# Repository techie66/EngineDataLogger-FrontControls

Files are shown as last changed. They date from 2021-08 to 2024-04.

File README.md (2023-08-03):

# Engine Data Logger - Front Controls

## Componenents
- [EngineDataLogger(EDL)](https://github.com/techie66/EngineDataLogger)
- [EDL - Dashboard](https://github.com/techie66/EngineDataLogger---Dashboard)
- ->[EDL - Front Controls](https://github.com/techie66/EngineDataLogger-FrontControls)
- [EDL - EngineData](https://github.com/techie66/EngineDataLogger-EngineData)

# Dependencies
- Seeed Studio CAN Library `git clone "https://github.com/Seeed-Studio/Seeed_Arduino_CAN.git"`
- NeoSWSerial `git clone "git@github.com:SlashDevin/NeoSWSerial.git"`

# License
EngineDataLogger is licensed under the GNU GPLv2. Dependencies are licensed under their respective licenses. See LICENSE for full text of GPLv2.

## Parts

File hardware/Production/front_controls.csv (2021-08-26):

Reference | Quantity | Value | Footprint | Datasheet | LCSC | Field4
A1 | 1 | Arduino_Nano_v3.x | NANO:Arduino_Nano | http://www.mouser.com/pdfdocs/Gravitech_Arduino_Nano3_0.pdf
C10 C9 C8 C7 C6 C5 C1 C2 C3 | 9 | .01uf | Capacitor_SMD:C_0402_1005Metric |  | C15195
C11 C12 | 2 | 33pf | Capacitor_SMD:C_0402_1005Metric | https://datasheet.lcsc.com/szlcsc/Guangdong-Fenghua-Advanced-Tech-0402CG330J500NT_C1562.pdf | C1562
C13 C14 C15 C16 | 4 | 100nf | Capacitor_SMD:C_0402_1005Metric | https://datasheet.lcsc.com/szlcsc/Samsung-Electro-Mechanics-CL05B104KO5NNNC_C1525.pdf | C1525
C17 | 1 | 330uf | Capacitor_THT:CP_Radial_D8.0mm_P3.50mm
C18 | 1 | 22nF | Capacitor_SMD:C_0603_1608Metric |  | C21122
C4 | 1 | .1uf | Capacitor_SMD:C_0402_1005Metric |  | C1525
Cboot1 | 1 | 0.1uf | Capacitor_SMD:C_0402_1005Metric |  | C1525
Chf1 | 1 | 220nf | Capacitor_SMD:C_0805_2012Metric |  | C5378
Cin1 | 1 | 10uf | Capacitor_SMD:C_0805_2012Metric |  | C440198
Cout1 Cout2 Cout3 Cout4 | 4 | 22uF | Capacitor_SMD:C_0805_2012Metric |  | C45783
D13 D12 D11 D10 D9 D8 | 6 | 4.7V Zener | Diode_SMD:D_SOD-323 |  | C136181
D19 D18 D17 D16 D15 D14 D1 D2 D3 D4 D5 D6 | 12 | D_Schottky | Diode_SMD:D_SOD-123 |  | C8598
D20 | 1 | 15V standoff | Diode_SMD:D_SMB | https://datasheet.lcsc.com/szlcsc/MDD-Jiangsu-Yutai-Elec-SMBJ15CA_C113989.pdf | C113989
D21 | 1 | 8A | Diode_SMD:D_SMC |  | C64338
D7 | 1 | 5.1V Zener | Diode_SMD:D_SOD-123 |  | C231290
H1 | 1 | CONN_01X10 | Pin_Headers:Pin_Header_Straight_1x10
H2 | 1 | HM-10 | Connector_PinSocket_2.54mm:PinSocket_1x06_P2.54mm_Vertical | ~
H3 | 1 | Expansion | Connector_PinHeader_2.54mm:PinHeader_2x08_P2.54mm_Vertical
H6 H5 H4 H7 | 4 | MountingHole | MountingHole:MountingHole_2.7mm_M2.5 | ~
J1 J2 J3 J4 J5 J6 J7 J8 J9 | 9 | Conn_01x02 | Connector_JST:JST_EH_B2B-EH-A_1x02_P2.50mm_Vertical
J10 J11 | 2 | CAN | Connector_JST:JST_EH_B2B-EH-A_1x02_P2.50mm_Vertical
JP1 | 1 | Jumper_NO_Small | Jumper:SolderJumper-2_P1.3mm_Open_RoundedPad1.0x1.5mm
L1 | 1 | 8.2uH, 60m | Inductor_SMD:L_Bourns_SRP7028A_7.3x6.6mm |  | C408450
P2 P1 | 2 | PWR | Connector_JST:JST_EH_B2B-EH-A_1x02_P2.50mm_Vertical
R0 R1 R2 R3 R4 R5 R6 R7 R8 | 9 | 500R | Resistor_SMD:R_0402_1005Metric |  | C25130
R11 R45 | 2 | 4k7 | Resistor_SMD:R_0603_1608Metric |  | C23162
R37 R34 R31 R28 R25 R22 R13 R17 R21 R43 R44 R47 | 12 | 100k | Resistor_SMD:R_0402_1005Metric |  | C25741
R38 R35 R32 R29 R26 R23 R12 R16 R20 R19 R15 R10 R18 R14 R9 | 15 | 1k | Resistor_SMD:R_0402_1005Metric |  | C11702
R39 R36 R33 R30 R27 R24 | 6 | 10R | Resistor_SMD:R_0402_1005Metric |  | C25077
R40 | 1 | 10k | Resistor_SMD:R_0603_1608Metric |  | C25804
R41 | 1 | 2k2 | Resistor_SMD:R_0603_1608Metric |  | C4190
R42 | 1 | 4K7 1% | Resistor_SMD:R_0402_1005Metric | https://datasheet.lcsc.com/szlcsc/Uniroyal-Elec-0402WGF4701TCE_C25900.pdf | C25900
R46 | 1 | 120R | Resistor_SMD:R_0402_1005Metric |  | C25079
R48 | 1 | 62K11 | Resistor_SMD:R_0603_1608Metric | ~ | C23221
Rfbb1 | 1 | 17k8 1% | Resistor_SMD:R_0402_1005Metric |  | C129766
Rfbt1 | 1 | 100k 1% | Resistor_SMD:R_0402_1005Metric |  | C25741
U1 | 1 | TXB0104PW | Package_SO:TSSOP-14_4.4x5mm_P0.65mm | http://www.ti.com/lit/ds/symlink/txb0104.pdf | C60708
U11 | 1 | LMR14030SDDA | NANO:LMR14030SDDA |  | C182078
U13 | 1 | MCP23017-E/SO | Package_SO:SOIC-28W_7.5x18.7mm_P1.27mm | https://datasheet.lcsc.com/szlcsc/Microchip-Tech-MCP23017-E-SO_C47023.pdf | C47023
U14 | 1 | MCP2515-xSO | Package_SO:SOIC-18W_7.5x11.6mm_P1.27mm | http://ww1.microchip.com/downloads/en/DeviceDoc/21801e.pdf | C12368
U15 | 1 | TJA1051T | Package_SO:SOIC-8_3.9x4.9mm_P1.27mm | http://www.nxp.com/documents/data_sheet/TJA1051.pdf | C6952
U6 U9 U8 U7 U5 U4 U10 U3 U2 | 9 | G3VM-31BR | G3VM-31BR:DIP762W50P254L737H485Q6 | IPC-7251 |  | OMRON
Y1 | 1 | 12Mhz | Crystal:Crystal_SMD_3225-4Pin_3.2x2.5mm | https://datasheet.lcsc.com/szlcsc/Yangxing-Tech-X322512MSB4SI_C9002.pdf | C9002

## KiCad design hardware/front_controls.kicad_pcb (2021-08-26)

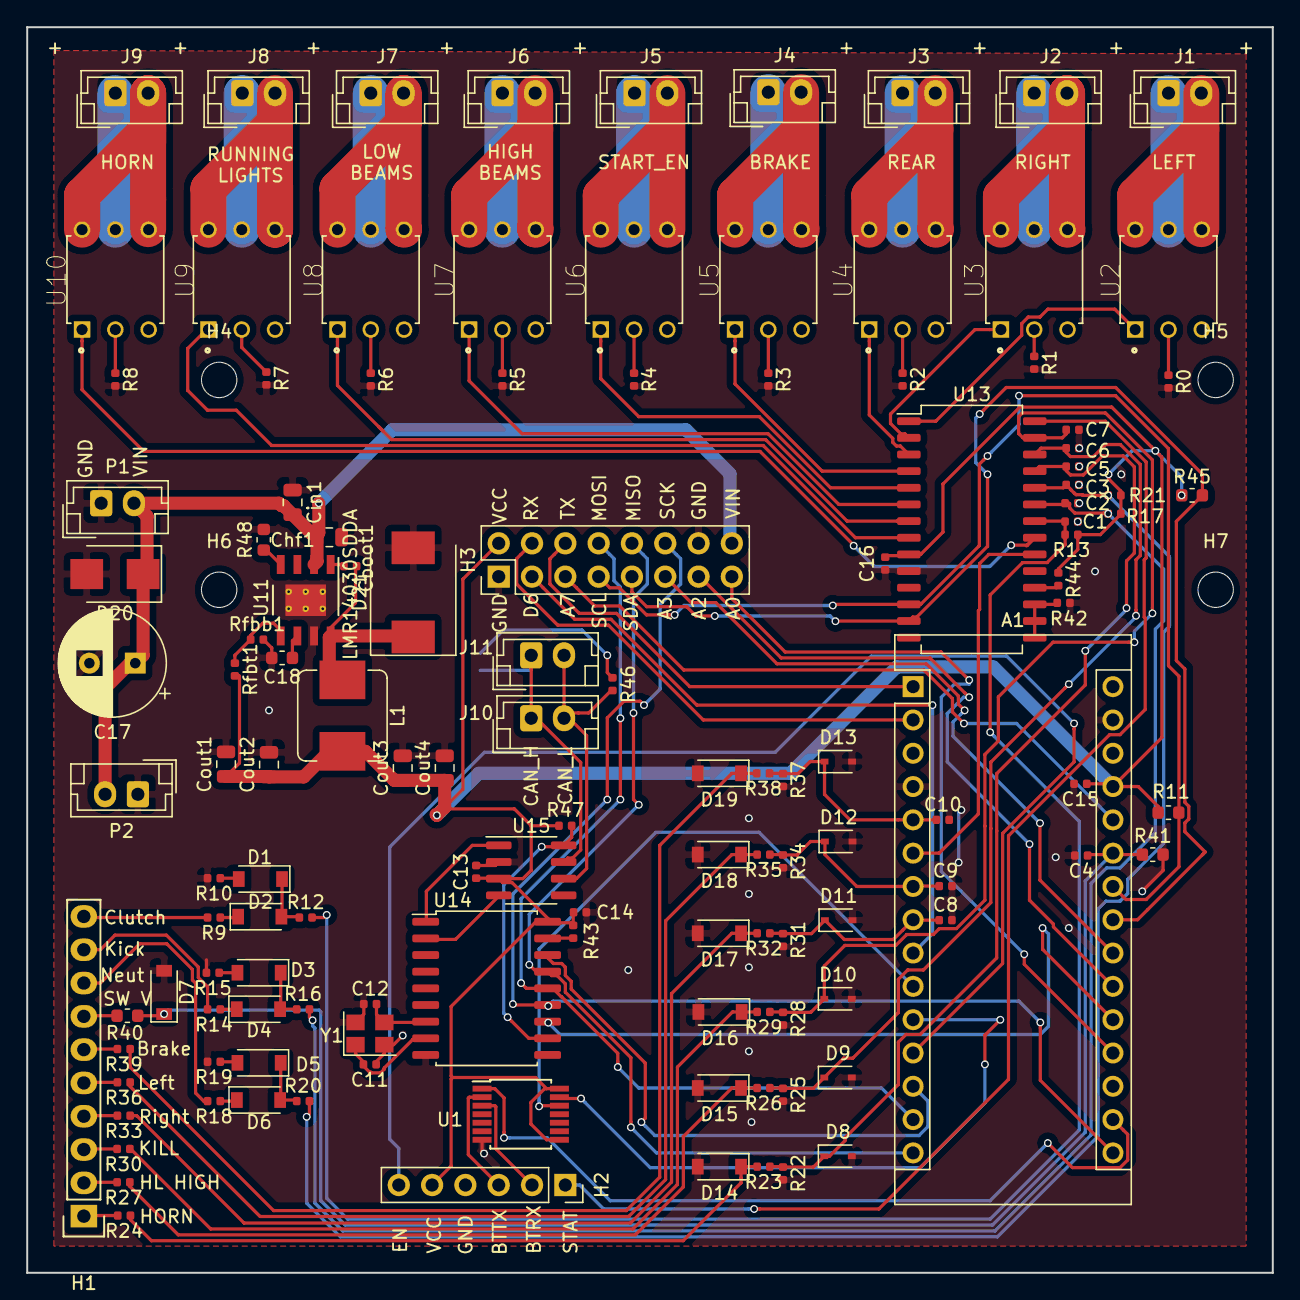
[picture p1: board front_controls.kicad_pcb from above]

Board: 2 copper layers, 95.0 x 95.0 mm, 135 parts (1 on the bottom side), 112 nets.

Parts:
A1: Arduino_Nano_v3.x; Arduino_Nano
C1, C2, C3, C5, C6, C7, C8, C9, C10: .01uf; C_0402_1005Metric
C4: .1uf; C_0402_1005Metric
C11, C12: 33pf; C_0402_1005Metric
C13, C14, C15, C16: 100nf; C_0402_1005Metric
C17: 330uf; CP_Radial_D8.0mm_P3.50mm
C18: 22nF; C_0603_1608Metric
Cboot1: 0.1uf; C_0402_1005Metric
Chf1: 220nf; C_0805_2012Metric
Cin1: 10uf; C_0805_2012Metric
Cout1, Cout2, Cout3, Cout4: 22uF; C_0805_2012Metric
D1, D2, D3, D4, D5, D6, D14, D15, D16, D17, D18, D19: D_Schottky; D_SOD-123
D7: 5.1V Zener; D_SOD-123
D8, D9, D10, D11, D12, D13: 4.7V Zener; D_SOD-323
D20: 15V standoff; D_SMB
D21: 8A; D_SMC
H1: CONN_01X10; Pin_Header_Straight_1x10
H2: HM-10; PinSocket_1x06_P2.54mm_Vertical
H3: Expansion; PinHeader_2x08_P2.54mm_Vertical
H4, H5, H6, H7: MountingHole; MountingHole_2.7mm_M2.5
J1, J2, J3, J4, J5, J6, J7, J8, J9: Conn_01x02; JST_EH_B2B-EH-A_1x02_P2.50mm_Vertical
J10, J11: CAN; JST_EH_B2B-EH-A_1x02_P2.50mm_Vertical
JP1: Jumper_NO_Small; SolderJumper-2_P1.3mm_Open_RoundedPad1.0x1.5mm
L1: 8.2uH, 60m; L_Bourns_SRP7028A_7.3x6.6mm
P1, P2: PWR; JST_EH_B2B-EH-A_1x02_P2.50mm_Vertical
R0, R1, R2, R3, R4, R5, R6, R7, R8: 500R; R_0402_1005Metric
R9, R10, R12, R14, R15, R16, R18, R19, R20, R23, R26, R29, R32, R35, R38: 1k; R_0402_1005Metric
R11, R45: 4k7; R_0603_1608Metric
R13, R17, R21, R22, R25, R28, R31, R34, R37, R43, R44, R47: 100k; R_0402_1005Metric
R24, R27, R30, R33, R36, R39: 10R; R_0402_1005Metric
R40: 10k; R_0603_1608Metric
R41: 2k2; R_0603_1608Metric
R42: 4K7 1%; R_0402_1005Metric
R46: 120R; R_0402_1005Metric
R48: 62K11; R_0603_1608Metric
Rfbb1: 17k8 1%; R_0402_1005Metric
Rfbt1: 100k 1%; R_0402_1005Metric
U1: TXB0104PW; TSSOP-14_4.4x5mm_P0.65mm
U2, U3, U4, U5, U6, U7, U8, U9, U10: G3VM-31BR; DIP762W50P254L737H485Q6
U11: LMR14030SDDA
U13: MCP23017-E/SO; SOIC-28W_7.5x18.7mm_P1.27mm
U14: MCP2515-xSO; SOIC-18W_7.5x11.6mm_P1.27mm
U15: TJA1051T; SOIC-8_3.9x4.9mm_P1.27mm
Y1: 12Mhz; Crystal_SMD_3225-4Pin_3.2x2.5mm

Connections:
/3V3: A1.17, U1.1
/BT_EN: A1.12, H2.6
/BT_RX_H: A1.10, U1.12
/BT_RX_L: H2.2, U1.3
/BT_STATE: H2.1, U13.28
/BT_TX_H: A1.11, U1.13
/BT_TX_L: H2.3, U1.2
/CAN_H: J10.1, J11.1, JP1.1, U15.7
/CAN_INT: A1.20, U14.12
/CAN_L: J10.2, J11.2, R46.1, U15.6
/EN_TX: R47.1, U14.11, U15.8
/INTA1: A1.6, U13.20
/IN_AN1: A1.25, C4.1, D7.1, R40.2, R41.1
/IN_BRAKE: A1.5, C10.1, D13.1, R37.1, R38.1
/IN_CLUTCH: C1.1, R12.2, R13.2, U13.22
/IN_HL_HIGH: C6.1, D9.1, R25.1, R26.1, U13.26
/IN_HORN: C5.1, D8.1, R22.1, R23.1, U13.25
/IN_KICK: C2.1, R16.2, R17.2, U13.23
/IN_KILL: C7.1, D10.1, R28.1, R29.1, U13.27
/IN_LEFT: A1.7, C9.1, D12.1, R34.1, R35.1
/IN_NEUTRAL: C3.1, R20.2, R21.2, U13.24
/IN_RIGHT: A1.8, C8.1, D11.1, R31.1, R32.1
/MCU_A0: A1.19, H3.15
/MCU_A2: A1.21, H3.13
/MCU_A3: A1.22, H3.11
/MCU_A7: A1.26, H3.5
/MCU_D6: A1.9, H3.3
/OUT_BRAKE: U5.1, U13.4
/OUT_HL_HIGH: U7.1, U13.6
/OUT_HL_LOW: U8.1, U13.7
/OUT_HORN: U10.1, U13.21
/OUT_LEFT: U2.1, U13.1
/OUT_REAR: U4.1, U13.3
/OUT_RIGHT: U3.1, U13.2
/OUT_RUNNING: U9.1, U13.8
/OUT_START_EN: U6.1, U13.5
/RXCAN: U14.2, U15.4
/SCL: A1.24, H3.7, R11.1, U13.12
/SDA: A1.23, H3.9, R45.2, U13.13
/SPI_CS: A1.13, U14.16
/SPI_SCK: A1.16, H3.12, U14.13
/SPI_SI: A1.14, H3.8, U14.14
/SPI_SO: A1.15, H3.10, U14.15
/TXCAN: U14.1, U15.1
/UART_RX: A1.2, H3.4
/UART_TX: A1.1, H3.6
/VIN: C17.1, Chf1.2, Cin1.2, D20.1, H3.16, P1.2, P2.2, U11.2
GND: A1.4, A1.29, C1.2, C2.2, C3.2, C4.2, C5.2, C6.2, C7.2, C8.2, C9.2, C10.2, C11.1, C12.1, C13.2, C14.1, C15.2, C16.2, C17.2, C18.2, Chf1.1, Cin1.1, Cout1.2, Cout2.2, Cout3.2, Cout4.2, D7.2, D8.2, D9.2, D10.2, D11.2, D12.2, D13.2, D14.2, D15.2, D16.2, D17.2, D18.2, D19.2, D20.2, D21.2, H2.4, H3.1, H3.14, P1.1, P2.1, R0.2, R1.2, R2.2, R3.2, R4.2, R5.2, R6.2, R7.2, R8.2, R10.2, R15.2, R19.2, R22.2, R25.2, R28.2, R31.2, R34.2, R37.2, R41.2, R42.2, R48.2, Rfbb1.2, U1.7, U11.7, U11.9, U13.10, U14.9, U15.2, Y1.2, Y1.4
unnamed: C11.2, U14.8, Y1.1
unnamed: C12.2, U14.7, Y1.3
unnamed: C18.1, U11.6
unnamed: Cboot1.1, U11.1
unnamed: Cboot1.2, D21.1, L1.1, U11.8
unnamed: D1.1, R9.1
unnamed: D1.2, D2.1, R12.1
unnamed: D2.2, R10.1
unnamed: D3.1, R14.1
unnamed: D3.2, D4.1, R16.1
unnamed: D4.2, R15.1
unnamed: D5.1, R18.1
unnamed: D5.2, D6.1, R20.1
unnamed: D6.2, R19.1
unnamed: D14.1, R23.2, R24.1
unnamed: D15.1, R26.2, R27.1
unnamed: D16.1, R29.2, R30.1
unnamed: D17.1, R32.2, R33.1
unnamed: D18.1, R35.2, R36.1
unnamed: D19.1, R38.2, R39.1
unnamed: H1.1, R24.2
unnamed: H1.2, R27.2
unnamed: H1.3, R30.2
unnamed: H1.4, R33.2
unnamed: H1.5, R36.2
unnamed: H1.6, R39.2
unnamed: H1.7, R40.1
unnamed: H1.8, R18.2
unnamed: H1.9, R14.2
unnamed: H1.10, R9.2
unnamed: J1.1, U2.5
unnamed: J1.2, U2.6
unnamed: J2.1, U3.5
unnamed: J2.2, U3.6
unnamed: J3.1, U4.5
unnamed: J3.2, U4.6
unnamed: J4.1, U5.5
unnamed: J4.2, U5.6
unnamed: J5.1, U6.5
unnamed: J5.2, U6.6
unnamed: J6.1, U7.5
unnamed: J6.2, U7.4, U7.6
unnamed: J7.1, U8.5
unnamed: J7.2, U8.4, U8.6
unnamed: J8.1, U9.5
unnamed: J8.2, U9.6
unnamed: J9.1, U10.5
unnamed: J9.2, U10.6
unnamed: JP1.2, R46.2
unnamed: R0.1, U2.2
unnamed: R1.1, U3.2
unnamed: R2.1, U4.2
unnamed: R3.1, U5.2
unnamed: R4.1, U6.2
unnamed: R5.1, U7.2
unnamed: R6.1, U8.2
unnamed: R7.1, U9.2
unnamed: R8.1, U10.2
unnamed: R42.1, U13.15, U13.16, U13.17
unnamed: R43.1, U14.17
unnamed: R44.2, U13.18
unnamed: R48.1, U11.4
unnamed: Rfbb1.1, Rfbt1.1, U11.5
VCC: A1.27, C13.1, C14.2, C15.1, C16.1, Cout1.1, Cout2.1, Cout3.1, Cout4.1, H2.5, H3.2, L1.2, R11.2, R13.1, R17.1, R21.1, R43.2, R44.1, R45.1, R47.2, Rfbt1.2, U1.8, U1.14, U13.9, U14.18, U15.3

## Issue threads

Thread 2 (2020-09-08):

Expand IO / CAN BUS interface

techie66, 2020-09-08:
Possible components:
TJA1050 - High speed CAN transceiver
MCP2551 - High speed CAN transceiver
MCP2515 - SPI CAN controller
MCP2515 - SPI IO expander

techie66, 2021-05-18:
Prototype of hardware V2 is working with I2C MCP23017 expander and MCP2515. New board has header for further IO expansion. Software updated for new hardware. Will close with merge of hardware v2

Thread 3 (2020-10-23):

certain cases ignition enable is wrong state.

techie66, 2020-10-23:
Under certain conditions, yet to be determined, the kill switch must be on to turn off the keyless ignition. ie ignition enable doesn't go high when expected. When bike is started manually then shut off is one such case, which results in forcing the starter to turn over.

techie66, 2022-03-27:
Ignition power integration is possible with V2 board and additional relays on expansion port. No longer relevant even to me.

Closed 2022-03-27.

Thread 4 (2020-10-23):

kickstand logic not right

techie66, 2020-10-23:
Logic is incorrect for kickstand, allowing the bike to be in gear with clutch out and kickstand down.
That condition should disable ignition power.

techie66, 2021-03-16:
This will have to wait until the hardware is updated to actually control ignition power

techie66, 2022-03-27:
With the V2 hardware, which is now fairly old, I added a few relays to to the expansion port, enabling direct control of ignition power and the software supports it as well.

Closed 2022-03-27.

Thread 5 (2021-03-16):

Add voltage regulator on board

techie66, 2021-03-16:
Board is missing direct power, currently draws power from USB. The working prototype doesn't do that, and we need on board voltage regulator.

techie66, 2021-04-22:
Hardware rev 2.0 prototype made with regulator. It's not pushed to GitHub yet until I get a chance to test it.

techie66, 2021-05-18:
Testing has

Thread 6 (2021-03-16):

Integrate keyless ignition

techie66, 2021-03-16:
Prototype has completely separate module for keyless ignition. Ideally that functionality would be included on one board or at least on a daughter board.

techie66, 2021-05-18:
Hardware V2 has headers for hm10 BLE module and additional IO to support this. Just need the software now.

techie66, 2022-03-27:
With newest version of firmware and dashboard app, and the aforementioned BLE module and more relays on the expansion port, proof of concept works. The bike will turn on when the app connects. No security, authentication or anything is implemented yet. Do not use yet IRL

techie66, 2025-01-11:
Still no security, but routines added to use BLE module as CAN bridge that emulates function of CAN-Link. Waits for a specific CAN frame with specific payload in order to turn on main power. ie. less likely to be hacked, but still not secure...

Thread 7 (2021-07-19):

Neutral and clutch swapped

techie66, 2021-07-19:
inputs for neutral and clutch are swapped (?)
need to check it and get the right pins to match labels on the board.
#oops

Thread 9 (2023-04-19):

Feature: add wake (pin change) on switched power

techie66, 2023-04-19:
Should be a simple addition to wake from sleep when switched power goes from 0v to 12v with pin change interrupt.

techie66, 2023-08-19:
3ecf09e adds the feature

Closed 2023-08-19.

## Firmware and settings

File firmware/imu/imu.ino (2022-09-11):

/*

    EngineDataLogger-Front Controls -- component that runs on MCU for front controls
    Copyright (C) 2018-2020  Jacob Geigle jacob@geigle.me

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
    You should have received a copy of the GNU General Public License along
    with this program; if not, write to the Free Software Foundation, Inc.,
    51 Franklin Street, Fifth Floor, Boston, MA 02110-1301 USA.

*/


/*    Basic Idea
 *  loop reads all input pins and checks for serial commands
 *  create command word and sensor data stream
 *  send sensor data (limit rate by time, etc)
 *  call each action function
 *  each function performs small snippet based on command word (smallest action at a time)
 *    use static vars to maintain state (eg blinking = on first time, off second time)
 *    millis() to maintain timing and synchronization
 *  brake light on interrupt
 *    flash initially, steady until low
 *  horn sounds on interrupt
 *  
 *  Pins read full register at a time and bitmasking used heavily to execute commands
 *  
 *  brake()
 *  blinkRight()
 *  blinkLeft()
 *  hornSound()
 *  enableStart()
 *  hlMode()
 *  
 */

#include <avr/interrupt.h>
#include <avr/power.h>
#include <avr/sleep.h>
#include <Wire.h>
#include <mcp2515_can.h>
#include "MPU6050_imu.h"
#include "../pins.h"
#include "spin.h"
#include "../wdt.h"

uint8_t ADCSRA_save = 0;
volatile boolean brakeStart = false;
boolean engineStarted = false;
float systemVoltage = 0;
volatile uint8_t mcpA = 0; // Output buffer for GPIOA
volatile uint8_t mcpB = 0; // Output buffer for GPIOB


const uint8_t RLY_ON = HIGH;
const uint8_t RLY_OFF = LOW;
const unsigned long blinkDelay = 350;
const unsigned long SLEEP_DELAY = 120000;
const unsigned long BRAKE_FLASH_INTERVAL = 50;

//Constants for voltage divider
const int resistor1 = 991; //997 (992 meas)
const int resistor2 = 223; //236 (218 meas)
const float denominator = (float)resistor2 / (resistor1 + resistor2);

// Vars for inputs
bool BRAKE_ON = false;
bool LEFT_ON = false;
bool RIGHT_ON = false;
bool HORN_ON = false;
bool HIGH_BEAMS_ON = false;
bool KILL_ON = false;
bool CLUTCH_DISENGAGED = false;
bool IN_NEUTRAL = false;
bool KICKSTAND_UP = false;

// CAN Constants
const int SPI_CS_PIN = 10;
mcp2515_can CAN(SPI_CS_PIN); // Set CS pin

// Function Prototypes
void sleepNow ();
void readSensors();
ISR(TIMER1_COMPA_vect);
void brakeLight();
void hornSound();
void Wakeup_Routine();
void allRelaysOff ();
void sleepNow ();

void setup() {
  Serial.begin(115200);
  Serial.println("Startup initiated!");
  Wire.begin(); // wake up I2C bus
  Wire.setClock(400000); // 400kHz I2C clock. Comment this line if having compilation difficulties
  #ifdef __AVR__
  Wire.setWireTimeout(3000, true); //timeout value in uSec
  #endif

  Wire.beginTransmission(0x20);
  Wire.write(0x00); // IODIRA register
  Wire.write(0xFE); // set pin 0 of port A to output, 1-7 to input
  Wire.endTransmission();

  Wire.beginTransmission(0x20);
  Wire.write(0x01); // IODIRB register
  Wire.write(0x00); // set all of port B to outputs
  Wire.endTransmission();

  Wire.beginTransmission(0x20);
  Wire.write(0x04); // GPINTENA
  Wire.write(0xFE); // 1-7 enable interrupt
  Wire.endTransmission();

  Wire.beginTransmission(0x20);
  Wire.write(0x02); // IPOLA
  Wire.write(0x0E); // Pins 1-3 Inverted Polarity
  Wire.endTransmission();

  Wire.beginTransmission(0x20);
  Wire.write(0x0C); // GPPUA
  Wire.write(0x0E); // Pins 1-3 Pullup Enabled
  Wire.endTransmission();

  //Serial.println("I2c Done");
  //allRelaysOff();

  pinMode(brakeInPin, INPUT);
  pinMode(leftInPin, INPUT);
  pinMode(rightInPin, INPUT);
  pinMode(voltageInPin, INPUT); // Analog for Voltage
  
  // CAN Setup

  while (CAN_OK != CAN.begin(CAN_500KBPS,MCP_12MHz)) {             // init can bus : baudrate = 500k
	  Serial.println("CAN ERROR");
      delay(100);
  }


  //Serial.println("CAN Done");

  CAN.mcpPinMode(MCP_RX0BF,MCP_PIN_OUT);

  //Serial.println("Startup Complete!");
  //delay(1000);
  MPU_setup();
  Serial.println("MPU Complete");
  Serial.println("Setup Complete\n");

  watchdogSetup();
}
spinner *s = spin_new(utf8_pat1, "Working", UTF8_CHAR_WIDTH);

void loop() {
  wdt_reset();
  spin_drw(s);
  delay(50);
  // if programming failed, don't try to do anything
  if (!dmpReady) return;
  // read a packet from FIFO
  if (mpu.dmpGetCurrentFIFOPacket(fifoBuffer)) { // Get the Latest packet 

    // display Euler angles in degrees
    mpu.dmpGetQuaternion(&q, fifoBuffer);
    mpu.dmpGetGravity(&gravity, &q);
    mpu.dmpGetYawPitchRoll(ypr, &q, &gravity);
    uint16_t roll = ( (ypr[2] * 180 / M_PI) + 180 ) * 10;
    uint16_t pitch = ( (ypr[1] * 180 / M_PI) + 180 ) * 10;
    uint16_t yaw = ( (ypr[0] * 180 / M_PI) + 360 ) * 10;
    // Send CAN Packets
    static unsigned char stmp[8] = {0xCC, 0xCC, 0xCC, 0xCC, 0xCC, 0xCC, 0xCC, 0xCC};
      stmp[0] = (uint8_t)roll;
      stmp[1] = (uint8_t)(roll >> 8) & 0x0F;
      stmp[1] |= (uint8_t)((pitch << 4) & 0xF0);
      stmp[2] = (uint8_t)(pitch >> 4);
      stmp[3] = (uint8_t)(yaw);
      stmp[4] = (uint8_t)(yaw >> 8);
    CAN.sendMsgBuf(0x1cecff80, CAN_EXTID, 5, stmp);

    /*Serial.print("ypr\t");
    Serial.print(ypr[0] * 180 / M_PI);
    Serial.print("\t");
    Serial.print(ypr[1] * 180 / M_PI);
    Serial.print("\t");
    Serial.print(ypr[2] * 180 / M_PI);
    */



    // display real acceleration, adjusted to remove gravity
    mpu.dmpGetAccel(&aa, fifoBuffer);
    mpu.dmpGetLinearAccel(&aaReal, &aa, &gravity);
    uint16_t accX = ( 1000 * 20 ) + ( aaReal.x * (long)1000 * 9.80665 ) / 16384.0;
    uint16_t accY = ( 1000 * 20 ) + ( aaReal.y * (long)1000 * 9.80665 ) / 16384.0;
    uint16_t accZ = ( 1000 * 20 ) + ( aaReal.z * (long)1000 * 9.80665 ) / 16384.0;
    // Send CAN Packets
    static unsigned char acc_msg[8] = {0xCC, 0xCC, 0xCC, 0xCC, 0xCC, 0xCC, 0xCC, 0xCC};
    acc_msg[0] = (uint8_t)(accX);
    acc_msg[1] = (uint8_t)(accX >> 8);
    acc_msg[2] = (uint8_t)(accY);
    acc_msg[3] = (uint8_t)(accY >> 8);
    acc_msg[4] = (uint8_t)(accZ);
    acc_msg[5] = (uint8_t)(accZ >> 8);
    CAN.sendMsgBuf(0x1cecff81, CAN_EXTID, 6, acc_msg);

/*    Serial.print("areal\t");
    Serial.print(aaReal.x);
    Serial.print("\t");
    Serial.print(aaReal.y);
    Serial.print("\t");
    Serial.println(aaReal.z);
*/


  }
  
}


void readSensors()
{
  byte inputs=0;
  systemVoltage = ( analogRead(voltageInPin));
  systemVoltage = (systemVoltage / 1024) * 5.0;
  systemVoltage = systemVoltage / denominator;

  // Convert inputs to standard commands

  Wire.beginTransmission(0x20);
  Wire.write(0x12); // GPIOA
  Wire.endTransmission();
  Wire.requestFrom(0x20, 1);
  inputs=Wire.read();

  CLUTCH_DISENGAGED = (inputs & clutchInPin);
  KICKSTAND_UP = ( inputs & kickInPin );
  IN_NEUTRAL = ( inputs & neutralInPin );
  HORN_ON = ( inputs & hornInPin );
  HIGH_BEAMS_ON = ( inputs & hlhighInPin );
  KILL_ON = ( inputs & killInPin );
  if (inputs & B10000000 ) {
    //in btstate
  }
  BRAKE_ON = digitalRead(brakeInPin);
  LEFT_ON = digitalRead(leftInPin);
  RIGHT_ON = digitalRead(rightInPin);
}



ISR(TIMER1_COMPA_vect){
  // Interrupt called when time to toggle flashers
  
  // Hazards
  static bool initiate = true;
  if (RIGHT_ON && LEFT_ON) {
	  if (initiate) {
		  mcpB |= leftOutPin;
		  mcpB |= rightOutPin;
		  initiate = false;
	  }
  }
  else {
	  initiate = true;
  }


  //LEFT
  // Determine if blinking or not, bitmask
  if (LEFT_ON) { // Pin 4 of PortD
    //Toggle
	mcpB ^= leftOutPin;
  }
  else {
    // - Not, turn light on and exit
	mcpB &= (leftOutPin ^ 0xFF);
  }

  //RIGHT
  // Determine if blinking or not, bitmask
  if (RIGHT_ON) { // Pin 5 of PortD
    //Toggle
	mcpB ^= rightOutPin;
  }
  else {
    // - Not, turn light on and exit
	mcpB &= (rightOutPin ^ 0xFF);
  }

  if (LEFT_ON || RIGHT_ON) { // Either left, right or both, Pin 4 or 5 of PortD
    // Enable rear lights
	mcpB |= rearOutPin;
	mcpB &= (runningOutPin ^ 0xFF);
  }
  else { // Neither
    // Disable rear lights
	mcpB &= (rearOutPin ^ 0xFF);
	mcpB |= runningOutPin;
  }
}

void brakeLight() {
  /*
   * Initial turn on flashes before going steady until brake is released
   */
  static int i = 0;
  static bool brakeEngaged = false;
  static unsigned long brakeDelayStart = millis();
  unsigned long currentMillis = millis();
  
  if (brakeEngaged) {
    brakeStart=false;
  }
  
  if (BRAKE_ON) {
    if (brakeStart) {
      /*
       * if--else (i<14) construct prevents from tying up processor
       * while waiting for light to flash
       */
      
      if (i < 14) { // while loop would block for almost a second
        if (currentMillis > ( brakeDelayStart + BRAKE_FLASH_INTERVAL )) {
		  mcpB ^= brakeOutPin;
          brakeDelayStart = currentMillis;
          i++;
        }
      }
      else {
		mcpB |= brakeOutPin;
        brakeStart = false;
      }
      
    }
    else {
      mcpB |= brakeOutPin;
      brakeEngaged = true;
    }
  }
  else {
	mcpB &= (brakeOutPin ^ 0xFF);
    i = 0;
    brakeEngaged = false;
    brakeStart=true;
  }
}

void hornSound() {
  if (HORN_ON) {
	mcpA |= hornOutPin;
  }
  else {
	mcpA &= (hornOutPin ^ 0xFF);
  }
}


void Wakeup_Routine()
{
  sleep_disable();
  detachInterrupt(0);
  power_all_enable ();                                  // power everything back on
  ADCSRA = ADCSRA_save;
  CAN.wake();
  CAN.mcpDigitalWrite(MCP_RX0BF,LOW);
}

void allRelaysOff ()
{
  //Turns all relays off
 
  Wire.beginTransmission(0x20);
  Wire.write(0x12); // GPIOA
  Wire.write(0x00); // All Off
  Wire.endTransmission();

  Wire.beginTransmission(0x20);
  Wire.write(0x13); // GPIOB
  Wire.write(0x00); // All Off
  Wire.endTransmission();

}

void sleepNow ()
{
  allRelaysOff();
  CAN.mcpDigitalWrite(MCP_RX0BF,HIGH);
  CAN.sleep();
  cli();                                                //disable interrupts
  sleep_enable ();                                      // enables the sleep bit in the mcucr register
  attachInterrupt (0, Wakeup_Routine, RISING);          // wake up on RISING level on D2
  set_sleep_mode (SLEEP_MODE_PWR_DOWN);  
  ADCSRA_save = ADCSRA;
  ADCSRA = 0;                                           //disable the ADC
  sleep_bod_disable();                                  //save power                                              
  sei();                                                //enable interrupts
  sleep_cpu ();                                         // here the device is put to sleep
}

void doCmd()
{

  Wire.beginTransmission(0x20);
  Wire.write(0x12); // GPIOA register
  Wire.write(mcpA); // write outputs
  Wire.endTransmission();

  Wire.beginTransmission(0x20);
  Wire.write(0x13); // GPIOB register
  Wire.write(mcpB); // write outputs
  Wire.endTransmission();

}

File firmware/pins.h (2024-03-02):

// PORTD
const uint8_t brakeInPin = 2;
const uint8_t leftInPin = 4;
const uint8_t rightInPin = 5;

// 3.3V pins labeled BTTX and BTRX
const uint8_t BTRX = 7;
const uint8_t BTTX = 8;

// Bluetooth "EN"
const uint8_t BT_EN = 9;

// mcp2515 interrupt
#define CAN_INT A1
const int CAN_CS_PIN = 10;

// SPI Pins
// SPI_MOSI = 11;
// SPI_MISO = 12;
// SPI_SCK = 13; // turns on LED dim when active

// MCP_GPIOA
const uint8_t hornOutPin = B00000001;
const uint8_t clutchInPin = B00000010;
const uint8_t kickInPin = B00000100;
const uint8_t neutralInPin = B00001000;
const uint8_t hornInPin = B00010000;
const uint8_t hlhighInPin = B00100000;
const uint8_t killInPin = B01000000;
const uint8_t BTStatePin = B10000000;

// MCP_GPIOB
const uint8_t leftOutPin = B00000001;
const uint8_t rightOutPin = B00000010;
const uint8_t rearOutPin = B00000100;
const uint8_t killOutPin = B00000100; // Ignition (coils, ignition module)
const uint8_t brakeOutPin = B00001000;
const uint8_t startEnableOutPin = B00010000;
const uint8_t startOutPin = B00010000; // starter
const uint8_t hlhighOutPin = B00100000;
const uint8_t hllowOutPin = B01000000;
const uint8_t runningOutPin = B10000000;

// PORTC
const uint8_t voltageInPin = A6;


/*
 * Constants for Cmd flags
const uint8_t ENGINE_RUNNING = B10000000;       // serialCmdA
const uint8_t BRAKE_ON = B00000100;             //receivedCmdD
const uint8_t HORN_ON = B00001000;              //receivedCmdD
const uint8_t LEFT_ON = B00010000;              //receivedCmdD
const uint8_t RIGHT_ON = B00100000;             //receivedCmdD
const uint8_t HIGH_BEAMS_ON = B01000000;        //receivedCmdD
const uint8_t KILL_ON = B10000000;              //receivedCmdD

const uint8_t CLUTCH_DISENGAGED = B00000100;    //receivedCmdC
const uint8_t IN_NEUTRAL  = B00010000;          //receivedCmdC
const uint8_t KICKSTAND_UP = B00001000;         //receivedCmdC
 */

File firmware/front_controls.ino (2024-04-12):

/*

    EngineDataLogger-Front Controls -- component that runs on MCU for front controls
    Copyright (C) 2018-2020  Jacob Geigle jacob@geigle.me

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
    You should have received a copy of the GNU General Public License along
    with this program; if not, write to the Free Software Foundation, Inc.,
    51 Franklin Street, Fifth Floor, Boston, MA 02110-1301 USA.

*/


/*    Basic Idea
 *  loop reads all input pins and checks for serial commands
 *  create command word and sensor data stream
 *  send sensor data (limit rate by time, etc)
 *  call each action function
 *  each function performs small snippet based on command word (smallest action at a time)
 *    use static vars to maintain state (eg blinking = on first time, off second time)
 *    millis() to maintain timing and synchronization
 *  brake light on interrupt
 *    flash initially, steady until low
 *  horn sounds on interrupt
 *  
 *  Pins read full register at a time and bitmasking used heavily to execute commands
 *  
 *  brake()
 *  blinkRight()
 *  blinkLeft()
 *  hornSound()
 *  enableStart()
 *  hlMode()
 *  
 */


#include <avr/interrupt.h>
#include <avr/power.h>
#include <avr/sleep.h>
#include <Wire.h>

#include <mcp2515_can.h>
#include <NeoSWSerial.h>

#include "wdt.h"
#include "pins.h"
#include "functions.h"
#include "ATCommands.h"

#define BTPOWER 1
#define BT_HW_SERIAL
//#define FR_DEBUG
#define FC_CMD_ID 0x226
#define UNLOCK_ID 0x267
#define IMU_POS_ID 0x1CECFF80
#define OBD_ADDRESS 0x7EA
#define AT_WORKING_BUFFER_SIZE 255

uint8_t inputCmdD; // pins 0-7
uint8_t inputCmdB; // pins 8-13 (two high bits unusable) (all outputs)
uint8_t inputCmdC; // analog pins A0-A5 (two high bits unuseable ATMega328p)
uint8_t serialCmdD = 0;
uint8_t serialCmdB = 0; // Extra Input, used for overrides D
uint8_t serialCmdC = 0;
uint8_t serialCmdA = 0; // Extra Input, used for overrides C
uint8_t receivedCmdD;
uint8_t receivedCmdC;
bool powerOn = false;
bool monitor_canbus = false;
bool igUnlocked = false;
#ifndef BT_HW_SERIAL
NeoSWSerial BTSerial(BTTX, BTRX); // RX, TX (TX->RX)
#else
  #define BTSerial Serial
#endif
int yaw;
const uint8_t mainOutPin = 6;
const uint8_t auxOutPin = A3;

ATCommands AT;

/********OUTPUTS***************
Left
Right
Horn
hlHigh
hlLow
Brake
startenable
rear
inverted rear (running lights?)
******************************/
/********INPUTS****************
Brake
Horn
Left
Right
hlHigh
Kill
clutch
neutral
voltage
******************************/

const uint8_t CMD_SIZE = 4;  // WIP see doCmd()
const uint16_t SERIAL_OUT_RATE = 200;
const unsigned long SERIAL_EXPIRE = 4000;
const unsigned long POWER_DOWN_DELAY = 2000;

// Constants for Cmd flags
const uint8_t ENGINE_RUNNING = B10000000;       // serialCmdA

//ADD MORE HERE

/**
 * @brief recvCmd
 * Read incoming commands and respond/act accordingly.
 *   Originally written for commands over serial, this now
 *   handles getting CAN packets and responding to requests.
 *   Does not handle commands from bluetooth serial. (ATCommands)
 *   Other CAN packets (ie periodic) are sent elsewhere
 *   see: at_sh_write(), sendData(), AT.update()
 * @param none
 * @return void
*/
void recvCmd() {
  // read CMD_SIZE command from serial(USB)
  unsigned long currentMillis = millis();
  static unsigned long lastMillis = 0;

  if (currentMillis > lastMillis + SERIAL_EXPIRE) {
    serialCmdD = 0;
    serialCmdB = 0;
    serialCmdC = 0;
    serialCmdA &= ENGINE_RUNNING; // Don' ENGINE_RUNNING automatically, assume still running
    lastMillis = currentMillis;
  }

#ifndef BT_HW_SERIAL
  static uint8_t receivedByte[(CMD_SIZE+1)];
  static uint8_t numBytesRecv = (CMD_SIZE+1);
  boolean goodRead = false;
  while (Serial.available() > 0) {
    if (numBytesRecv < CMD_SIZE) {
      receivedByte[numBytesRecv] = Serial.read();
      numBytesRecv++;
    }
    else if (numBytesRecv == CMD_SIZE) {
      if ((char)Serial.read() == 'Z') {
        // End Character. Presumably good data
        goodRead = true;
        numBytesRecv++;
        break;
      }
    }
    else if (numBytesRecv > CMD_SIZE) {
      if ((char)Serial.read() == 'A') {
        // Start Character
        numBytesRecv = 0;
      }
    }
  }

  if (goodRead) {
    // Written for CMD_SIZE = 4
    
    serialCmdD = receivedByte[0]; // Equivalent to PIND
    serialCmdB = receivedByte[1]; // Overrides for PIND
    serialCmdC = receivedByte[2]; // Equivalent to PINC
    serialCmdA = receivedByte[3]; // Overrides for PINC
    // zero out local vars
    //numBytesRecv = 0;
    goodRead = false;
    for (uint8_t i = 0; i < (CMD_SIZE+1); i++ ) {
      receivedByte[i] = 0;
    }
    // Set Time of last received CMD
    lastMillis = currentMillis;
  }
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

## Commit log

2019-03-16 Initial commit with fairly well tested code. Had been developed previously with Arduino library before switching to Make and git.
2020-09-08 Folder structure. PCB KiCAD files.
    [front_controls-B_Cu.gbr, front_controls-B_Mask.gbr, front_controls-B_SilkS.gbr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]
2021-04-18 Version 2 hardware files
    [front_controls-B_Cu.gbr, front_controls-B_Mask.gbr, front_controls-B_SilkS.gbr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]
2021-05-15 Hardware V2 major modifications
    [REG_SW_5V_LMR33630.sch, front_controls.kicad_pcb, front_controls.sch]
2021-05-15 Makefile options to work better with older tool-chains
2021-07-06 use new hardware power saving features
2021-07-09 Corrected low-power states for TJA1051T
    [front_controls.ino]
2021-08-26 Switched regulators to more available chip
    [REG_SW_5V_LMR140x0.sch, REG_SW_5V_LMR33630.sch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]
2021-09-15 Logic added for kill-switch output
2021-09-15 Added state var for powerOn
2021-09-15 Changed aux board to usable pin
2021-09-16 Basic power control via BLE module INSECURE, no auth or anything. ANY connection turns on the power. Some work with keeping the MLT-BT05 I have responsive and sleeping.
2021-09-17 Updated Killswitch/Kickstand Logic. Add power-off protection for BLE disconnects.
2022-08-01 gps, imu additional modules. WDT, CANSerial support. include spinner and pins defined in different header
2022-09-11 combined gps and imu to one device
2022-09-12 #defines for BLE power control, listens to CAN for incoming commands
2022-09-12 disable WDT on sleep, read CAN bus properly
2022-09-25 gps+imu: Disable WDT during setup, change MPU6050 address
2022-09-26 shrunk program size. fixed watchdog
    [MPU6050_imu.h, sketch.ino]
2022-10-26 save space on gps+imu, sleep, and power management. Split out some more common functions
2022-10-30 fixed to match actual hardware
    [MPU6050_imu.h, functions.h, sketch.ino]
2023-04-19 Assume engine running if voltage > 14. Helps keep headlight on if CAN fails
    [basic.ino, front_controls.ino, functions.h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]
2023-04-26 prevent race condition with BLE module, move a few pin definitions to pins.h
    [front_controls.ino, pins.h]
2023-08-03 Removed workaround for CAN library
    [front_controls.ino]
2023-08-04 Added missing interrupt vector, inserted delay in sleep routine.
    [front_controls.ino, functions.h]
2024-02-29 Update Kicad files
    [REG_SW_5V_LMR140x0.kicad_sch, REG_SW_5V_LMR33630.kicad_sch, front_controls.kicad_sch]
2024-04-12 Rate limit gps+imu. Rate limit BT.

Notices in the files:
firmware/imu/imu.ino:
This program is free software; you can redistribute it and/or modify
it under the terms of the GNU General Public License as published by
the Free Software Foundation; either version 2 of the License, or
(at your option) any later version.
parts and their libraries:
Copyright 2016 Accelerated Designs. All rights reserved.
